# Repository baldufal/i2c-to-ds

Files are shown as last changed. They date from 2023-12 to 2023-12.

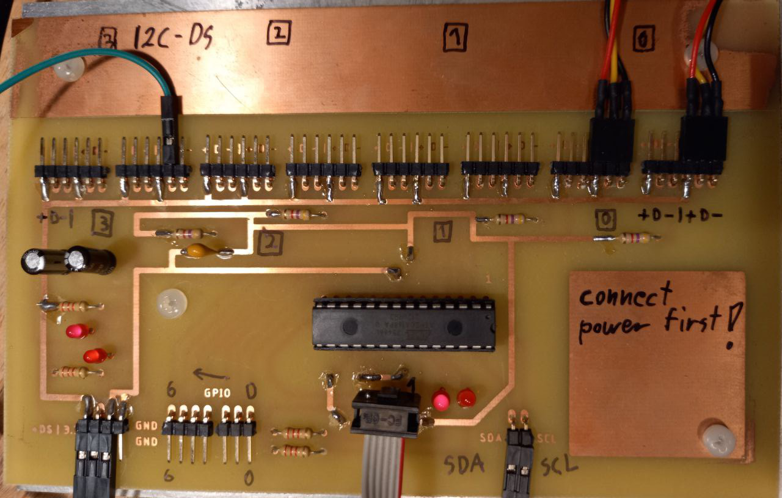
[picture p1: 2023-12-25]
Board/pcb.jpg

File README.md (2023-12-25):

# DS to I2C Expander
Software for Atmega**8 for connecting up to 40 DS18b20 devices to one I2C bus.

We have many DS sensors and didn't want to/couldn't connect them all to a Raspberry Pi due to lack of pins.
We therefore created a small breakout board with an ATmega168(L) on it to read the sensors and make readings available via I2C.
The devices are connected to 4 1-wire buses, which can be searched and read out through setting bits in the control register at `0x00`.

## Board
The board provides 4 independent 1-Wire buses with 4 3-pin connectors each.
The DS are powered by 5V, but the data line is pulled up to 3.3V (which is the supply voltage of the Atmega).

Additionally there are 7 GPIO pins on the board, that can also be controlled via I2C.

For monitoring/debugging, there are 2 LEDs that indicate working 3.3V and 5V voltages.
Another 2 LEDs are controlled by the mC and indicate healthy operation (blinking @ 1Hz) and ongoing readouts (second LED on).

## I2C Interface
The device address is `0x3f`.
The I2C interface exposes 254 8bit registers:
Register | Semantics | Allowed values (writing)
---|---|---
0 | Controlling 1-Wire buses | 1 / 2 / 4 / 8 / 16
1 | GPIO Data Direction | 0-127
2 | GPIO Values | 0-127
3 | CRC over following bytes| -
4 | Length n | -
5 | Data Byte 1 | -
6 | Data Byte 2| -
7 | ... | -
n+4 | Data Byte n-1 | -

- Register 1 allows reading/setting the data direction (input or output) of the 7 GPIO pins.
- Register 2 allows reading the state of input GPIOs and setting the state of output GPIOs.
- The CRC is the 1-Wire CRC8. It is computed over register 4 and the following (actually used!) data bytes (end defined by the content of register 4).
- Register 4 contains the number of data bytes that follow. All other registers will read as 0.

During 1-Wire operations, no I2C communication is possible (interrupts disabled)!

## 1-Wire commands
The four 1-Wire buses can be controlled by setting any of the 5 LSBs in the command register (only one at a time).

Bits 0 to 3 will trigger a device search on the corresponding 1-Wire bus.
After ~1s, the data bytes will contain an ordered list of all addresses on this bus.

Bit 4 will trigger the conversion (actual measurement of temperatures by DSs) of all devices on all buses.
After ~1s, the data bytes will contain the temperature data. This consists of 2 bytes per DS, as specified in the data sheet.

The conversion command depends on the 1-Wire addresses, that were previously found by the device search command(s).
A search on bus 0 will first reset all addresses. A search on any bus must not be triggered after a search on a bus with higher index was triggered.
It is thereby strongly advised to set bits 0 to 3 in this order for initialization and then only set bit 3 for readout.

## Test scripts
There are two python scripts, that allow sending 1-Wire commands and reading/setting GPIO values from a terminal on a Raspberry Pi.

## License
MIT, but would be nice if you would link back here.

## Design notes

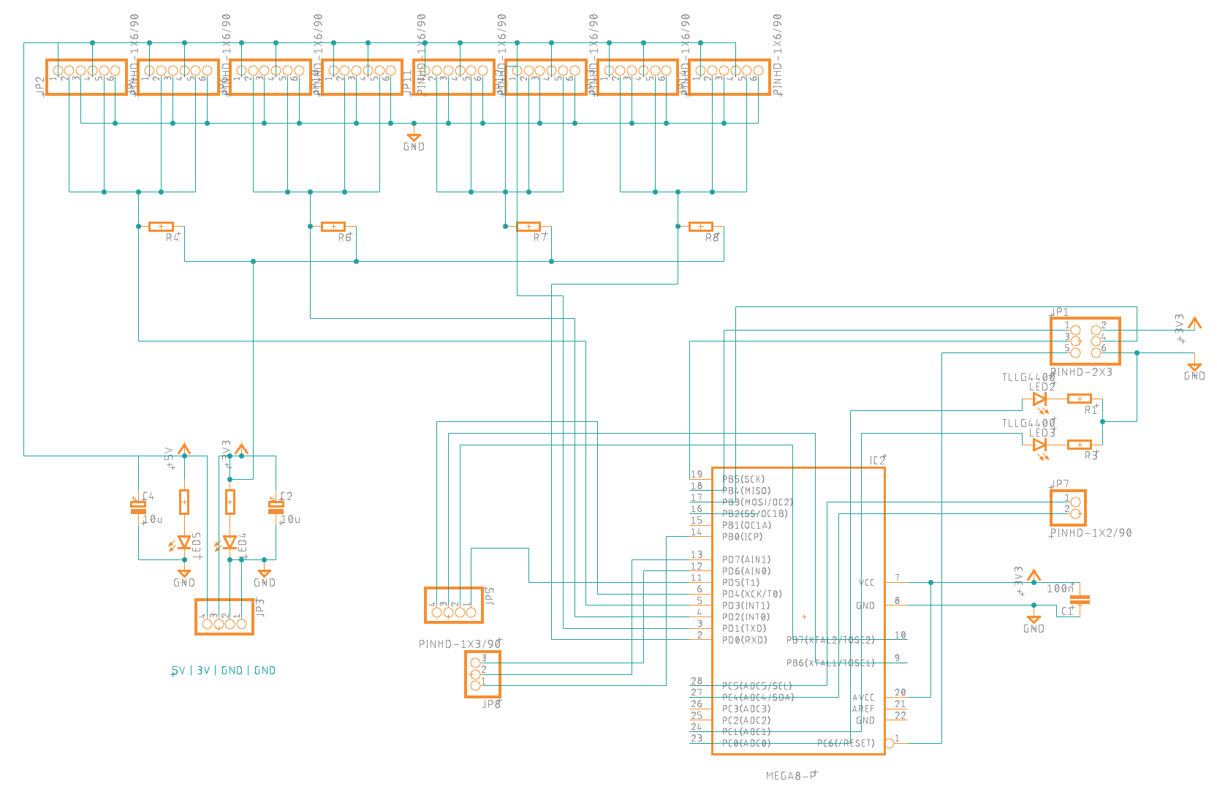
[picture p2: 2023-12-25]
Board/schematic.PNG

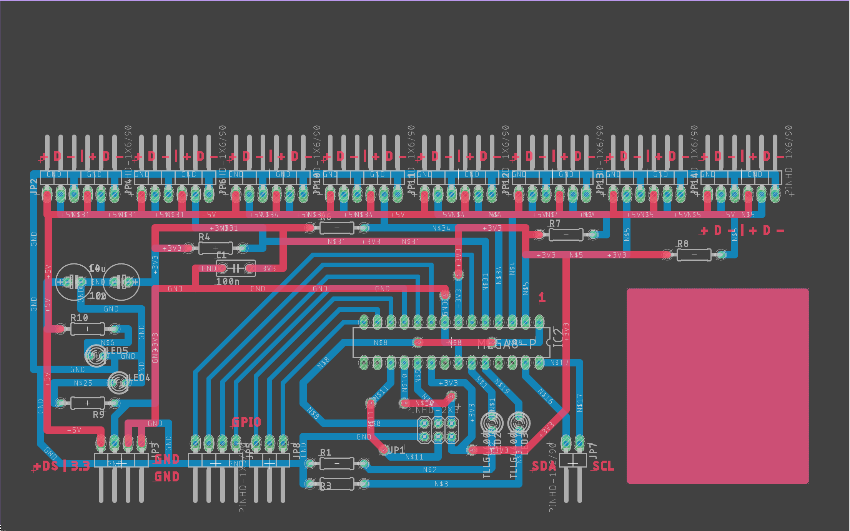
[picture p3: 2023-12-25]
Board/board.PNG

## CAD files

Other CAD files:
Board/I2C-DS ED v35.f3z

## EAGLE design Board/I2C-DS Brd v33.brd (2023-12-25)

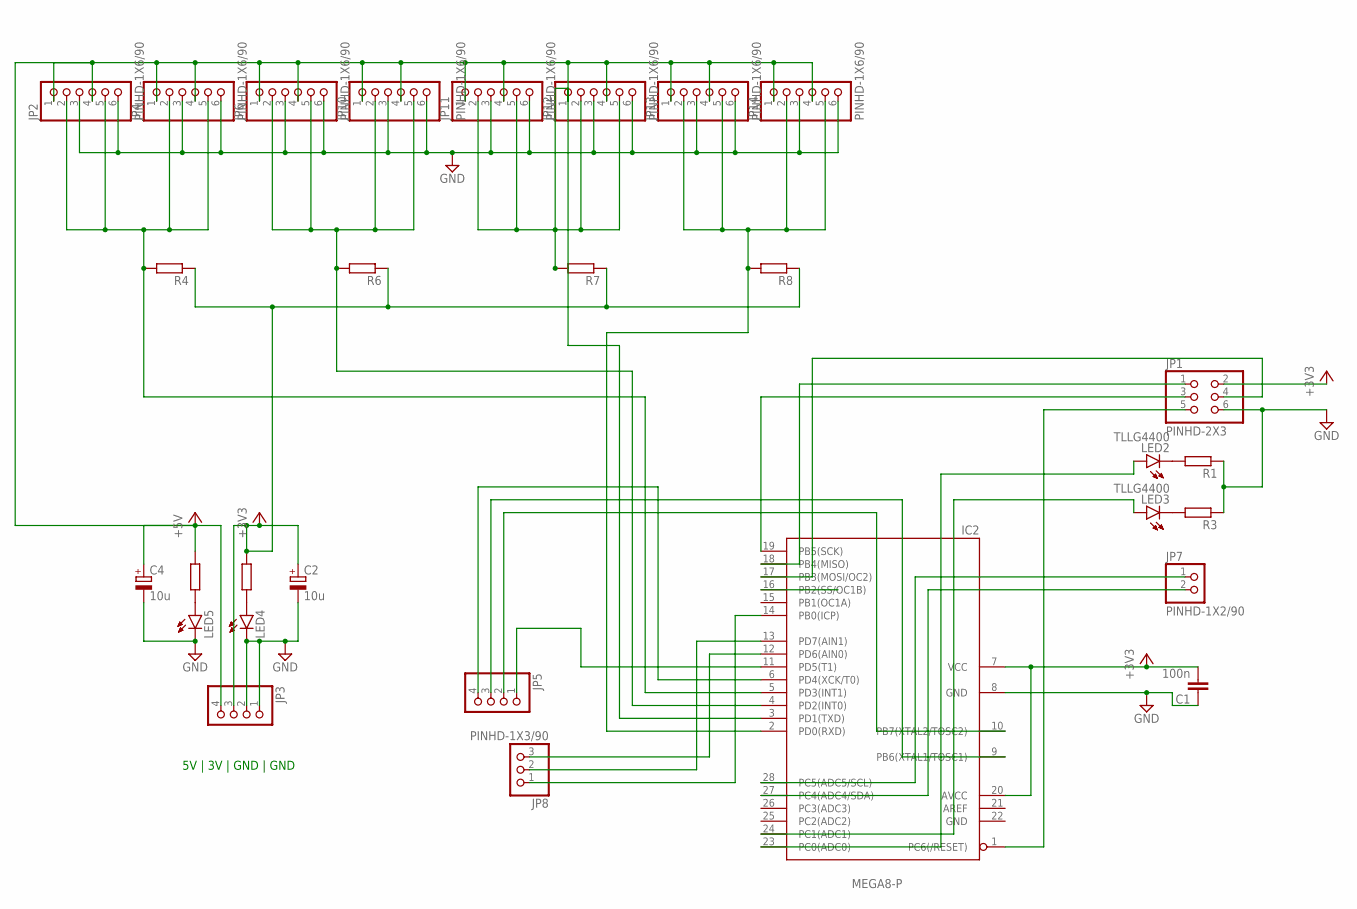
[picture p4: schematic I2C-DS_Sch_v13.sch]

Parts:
C1: 100n; C050-030X075
C2, C4: 10u; E2,5-7
IC2: MEGA8-P; DIL28-3
JP1: PINHD-2X3; 2X03
JP2, JP4, JP6, JP10, JP11, JP12, JP13, JP14: PINHD-1X6/90; 1X06/90
JP3, JP5: PINHD-1X4/90; 1X04/90
JP7: PINHD-1X2/90; 1X02/90
JP8: PINHD-1X3/90; 1X03/90
LED2, LED3: TLLG4400; LED3MM
LED4, LED5: LED3MM
R1, R3, R4, R6, R7, R8, R9, R10: R-EU_0207/10; 0207/10

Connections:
+3V3: C1.2, C2.+, IC2.7 (VCC), IC2.20 (AVCC), JP1.2, JP3.3, R4.1, R6.1, R7.1, R8.1, R9.1
+5V: C4.+, JP2.1, JP2.4, JP3.4, JP4.1, JP4.4, JP6.1, JP6.4, JP10.1, JP10.4, JP11.1, JP11.4, JP12.1, JP12.4, JP13.1, JP13.4, JP14.1, JP14.4, R10.1
GND: C1.1, C2.-, C4.-, IC2.8 (GND), IC2.22 (GND), JP1.6, JP2.3, JP2.6, JP3.1, JP3.2, JP4.3, JP4.6, JP6.3, JP6.6, JP10.3, JP10.6, JP11.3, JP11.6, JP12.3, JP12.6, JP13.3, JP13.6, JP14.3, JP14.6, LED4.K (C), LED5.K (C), R1.1, R3.1
unnamed: IC2.23 (PC0(ADC0)), LED2.A
unnamed: LED2.K (C), R1.2
unnamed: LED3.K (C), R3.2
unnamed: IC2.3 (PD1(TXD)), JP11.2, JP11.5, JP12.2, JP12.5, R7.2
unnamed: IC2.2 (PD0(RXD)), JP13.2, JP13.5, JP14.2, JP14.5, R8.2
unnamed: LED5.A, R10.2
unnamed: IC2.13 (PD7(AIN1)), JP8.2
unnamed: IC2.1 (PC6(/RESET)), JP1.5
unnamed: IC2.19 (PB5(SCK)), JP1.3
unnamed: IC2.18 (PB4(MISO)), JP1.1
unnamed: IC2.17 (PB3(MOSI/OC2)), JP1.4
unnamed: IC2.6 (PD4(XCK/T0)), JP5.4
unnamed: IC2.11 (PD5(T1)), JP5.1
unnamed: IC2.9 (PB6(XTAL1/TOSC1)), JP5.3
unnamed: IC2.10 (PB7(XTAL2/TOSC2)), JP5.2
unnamed: IC2.27 (PC4(ADC4/SDA)), JP7.2
unnamed: IC2.28 (PC5(ADC5/SCL)), JP7.1
unnamed: IC2.24 (PC1(ADC1)), LED3.A
unnamed: IC2.12 (PD6(AIN0)), JP8.3
unnamed: IC2.14 (PB0(ICP)), JP8.1
unnamed: LED4.A, R9.2
unnamed: IC2.5 (PD3(INT1)), JP2.2, JP2.5, JP4.2, JP4.5, R4.2
unnamed: IC2.4 (PD2(INT0)), JP6.2, JP6.5, JP10.2, JP10.5, R6.2

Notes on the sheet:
5V | 3V | GND | GND

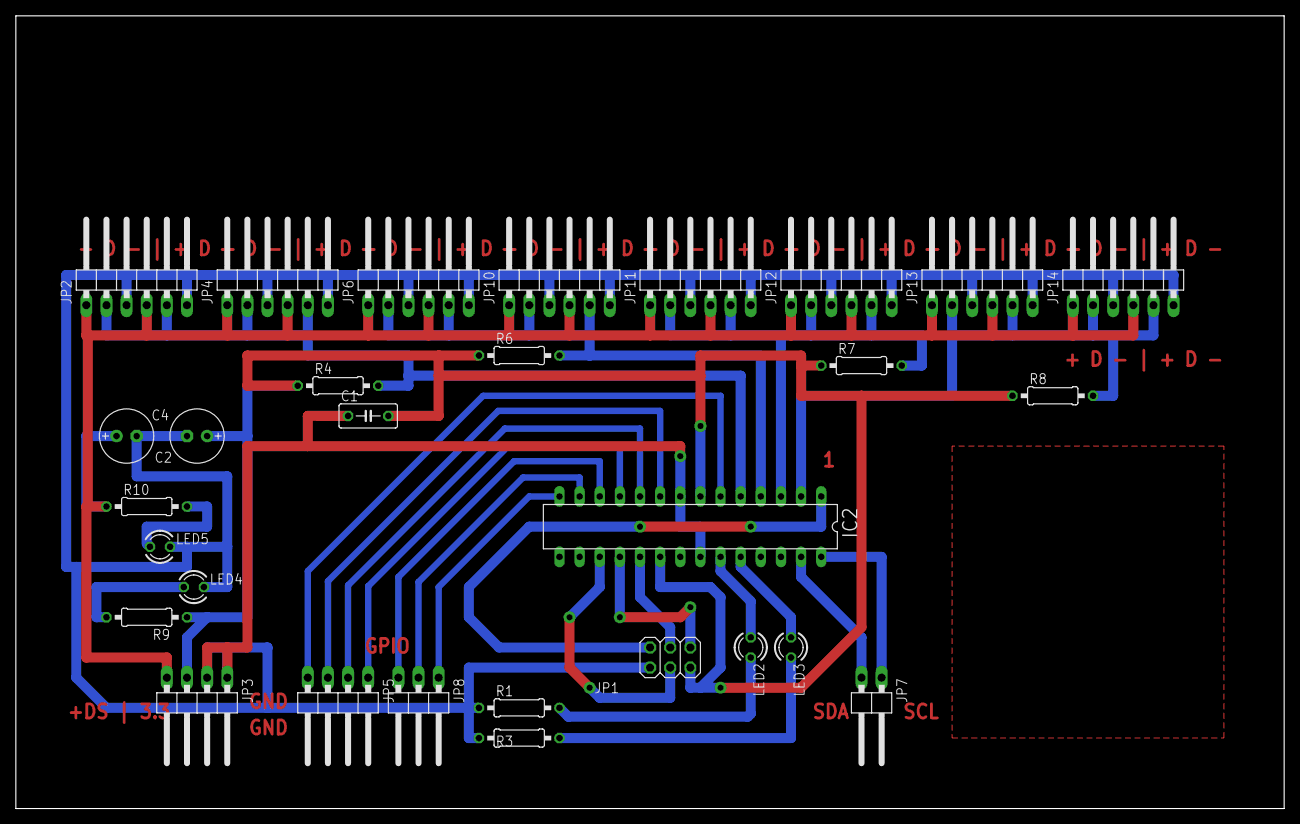
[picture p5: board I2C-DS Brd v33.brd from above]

Board: 2 copper layers, 160.0 x 100.0 mm, 29 parts (0 on the bottom side), 26 nets.

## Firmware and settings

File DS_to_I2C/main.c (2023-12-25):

// Inspired by https://gist.github.com/stecman/9ec74de5e8a5c3c6341c791d9c233adc

#ifndef F_CPU
# define F_CPU 8000000UL
#endif

//1Wire
#include "ds18b20.h"
#include "onewire.h"
#include "pindef.h"

//I2C
#include "twislave.h"

//CRC
#include "crc.h"

// AVR
#include <avr/io.h>
#include <util/delay.h>
#include <avr/interrupt.h>
#include <avr/wdt.h>

// C
#include <string.h>


// I2C slave address.
#define I2C_SLAVE_ADRESS 0x3F

// Status register flags.
#define BIT_INIT_BUS0 0x01
#define BIT_INIT_BUS1 0x02
#define BIT_INIT_BUS2 0x04
#define BIT_INIT_BUS3 0x08
#define BIT_READOUT 0x10



const static gpin_t busPins[4] = {
	{ &PORTD, &PIND, &DDRD, PIND0 },
	{ &PORTD, &PIND, &DDRD, PIND1 },
	{ &PORTD, &PIND, &DDRD, PIND2 },
	{ &PORTD, &PIND, &DDRD, PIND3 }};


	// Contains all known 1wire addresses. 8 Bytes each.
	// First all on bus 1, then bus 3, ...
	static uint8_t deviceAddresses[400];
	// Contains how many devices there are on bus 1 .. 4.
	static uint8_t deviceCounts[4];


	static void io_init(){
		// 1Wire busses: PD0..PD3
		// 7 "GPIO" pins: B0, D7, D6, D5, B7, B6, D4
		// LEDs: C0 (1Hz alive signal), C1 (="1Wire action in progress")
		
		// LEDs as outputs
		DDRC |= 0b00000011;
		// LEDs off
		PORTC &= ~0b00000011;
		
		// Bus and GPIO pins are continuously managed during execution
	}
	

	static void syncGPIO(){
		// 7 "GPIO" pins: B0, D7, D6, D5, B7, B6, D4
		
		// 0 -> B0
		if(i2cdata[1] & (1<<0)){
			DDRB |=  (1<< DDRB0);
			if(i2cdata[2] & (1<<0)){
				PORTB |= (1<<PORTB0);
				}else{
				PORTB &= ~(1<<PORTB0);
			}
			}else{
			DDRB &= ~(1<<DDRB0);
			i2cdata[2] &= ~(1<<0);
			if(PINB & (1<<PINB0))
			i2cdata[2] |= (1<<0);
		}
		// 1 -> D7
		if(i2cdata[1] & (1<<1)){
			DDRD |=  (1<< DDRD7);
			if(i2cdata[2] & (1<<1)){
				PORTD |= (1<<PORTD7);
				}else{
				PORTD &= ~(1<<PORTD7);
			}
			}else{
			DDRD &= ~(1<<DDRD7);
			i2cdata[2] &= ~(1<<1);
			if(PIND & (1<<PIND7))
			i2cdata[2] |= (1<<1);
		}
		// 2 -> D6
		if(i2cdata[1] & (1<<2)){
			DDRD |=  (1<< DDRD6);
			if(i2cdata[2] & (1<<2)){
				PORTD |= (1<<PORTD6);
				}else{
				PORTD &= ~(1<<PORTD6);
			}
			}else{
			DDRD &= ~(1<<DDRD6);
			i2cdata[2] &= ~(1<<2);
			if(PIND & (1<<PIND6))
			i2cdata[2] |= (1<<2);
		}
		// 3 -> D5
		if(i2cdata[1] & (1<<3)){
			DDRD |=  (1<< DDRD5);
			if(i2cdata[2] & (1<<3)){
				PORTD |= (1<<PORTD5);
				}else{
				PORTD &= ~(1<<PORTD5);
			}
			}else{
			DDRD &= ~(1<<DDRD5);
			i2cdata[2] &= ~(1<<3);
			if(PIND & (1<<PIND5))
			i2cdata[2] |= (1<<3);
		}
		// 4 -> B7
		if(i2cdata[1] & (1<<4)){
			DDRB |=  (1<< DDRB7);
			if(i2cdata[2] & (1<<4)){
				PORTB |= (1<<PORTB7);
				}else{
				PORTB &= ~(1<<PORTB7);
			}
			}else{
			DDRB &= ~(1<<DDRB7);
			i2cdata[2] &= ~(1<<4);
			if(PINB & (1<<PINB7))
			i2cdata[2] |= (1<<4);
		}
		// 5 -> B6
		if(i2cdata[1] & (1<<5)){
			DDRB |=  (1<< DDRB6);
			if(i2cdata[2] & (1<<5)){
				PORTB |= (1<<PORTB6);
				}else{
				PORTB &= ~(1<<PORTB6);
			}
			}else{
			DDRB &= ~(1<<DDRB6);
			i2cdata[2] &= ~(1<<5);
			if(PINB & (1<<PINB6))
			i2cdata[2] |= (1<<5);
		}
		// 6 -> D4
		if(i2cdata[1] & (1<<6)){
			DDRD |=  (1<< DDRD4);
			if(i2cdata[2] & (1<<6)){
				PORTD |= (1<<PORTD4);
				}else{
				PORTD &= ~(1<<PORTD4);
			}
			}else{
			DDRD &= ~(1<<DDRD4);
			i2cdata[2] &= ~(1<<6);
			if(PIND & (1<<PIND4))
			i2cdata[2] |= (1<<6);
		}
	}

	// Search all devices of a specific bus.
	// Result is written into deviceAddresses[] and i2cdata[].
	static void _searchDevices(uint8_t busIndex){
		memset(i2cdata + 3, 0, sizeof(i2cdata) -3);
		
		// Start index of this bus in deviceAddresses[].
		uint8_t addressStartIndex = 0;
		for(uint8_t i = 0; i < busIndex; i++){
			addressStartIndex += 8* deviceCounts[i];
		}
		onewire_reset(busPins + busIndex);
		
		// Prepare a new device search
		onewire_search_state search;
		onewire_search_init(&search);
		
		// Search and dump temperatures until we stop finding devices
		uint8_t foundDevices = 0;
		while (onewire_search(busPins + busIndex, &search)) {
			if (onewire_check_rom_crc(&search)) {
				memcpy(deviceAddresses + addressStartIndex + 8 * foundDevices, search.address, sizeof(search.address));
			}
			foundDevices++;
		}
		deviceCounts[busIndex] = foundDevices;
		
		// Write data to i2c registers.
		uint8_t length = deviceCounts[busIndex] * 8;
		i2cdata[4] = length;
		memcpy(i2cdata + 5, deviceAddresses + addressStartIndex, length);
		i2cdata[3] = crc8(i2cdata + 4, length + 1);
	}

	// Read all devices of a specific bus.
	// Result is written into i2cdata[].
	static void _readDevices(uint8_t busIndex){
		// Start index of this bus in deviceAddresses[].
		uint8_t addressStartIndex = 0;
		// Start index of this bus in i2cdata[].
		uint8_t i2cStartIndex = 5;
		for(uint8_t i = 0; i < busIndex; i++){
			addressStartIndex += 8 * deviceCounts[i];
			i2cStartIndex += 2 * deviceCounts[i];
		}
		
		for(uint8_t i = 0; i < deviceCounts[busIndex]; i++){
			uint16_t reading = ds18b20_read_slave(busPins + busIndex, deviceAddresses + addressStartIndex + 8 * i);
			//uint8_t i2cIndex = i2cStartIndex + 2 * i;
			//reading = (i2cIndex << 8) | busIndex; // For debugging only.
			memcpy(i2cdata + i2cStartIndex + 2 * i, &reading, sizeof(reading));
		}
	}


	static void handleStatusByte(){
		// Return if nothing to do
		if((i2cdata[0] & 0b00011111) == 0x00)
		return;
		
		// Enable readout LED
		PORTC |= 0x02;
		
		switch(i2cdata[0]){
			case BIT_INIT_BUS0:
			// When initializing bus 0 we reset all known addresses.
			memset(deviceAddresses, 0, sizeof(deviceAddresses));
			memset(deviceCounts, 0, sizeof(deviceCounts));
			
			_searchDevices(0);
			break;
			
			case BIT_INIT_BUS1:
			_searchDevices(1);
			break;
			
			case BIT_INIT_BUS2:
			_searchDevices(2);
			break;
			
			case BIT_INIT_BUS3:
			_searchDevices(3);
			break;
			
			case BIT_READOUT:
			{
				// Start conversion
				ds18b20_convert(busPins + 0);
				ds18b20_convert(busPins + 1);
				ds18b20_convert(busPins + 2);
				ds18b20_convert(busPins + 3);
				
				/*
				// Start conversion for every device independently.
				uint8_t addressStartIndex = 0;
				for(uint8_t busIndex = 0; busIndex < 4; busIndex++){
				for(uint8_t deviceIndex = addressStartIndex; deviceIndex < addressStartIndex + deviceCounts[busIndex]; deviceIndex++){
				ds18b20_convert_single(busPins + busIndex,deviceAddresses + 8 * deviceIndex);
				}
				addressStartIndex += deviceCounts[busIndex];
				}
				*/
				
				// Wait for conversion to complete.
				_delay_ms(750);
				
				// Clear result.
				memset(i2cdata + 3, 0, sizeof(i2cdata) - 3);
				
				// Get results.
				_readDevices(0);
				_readDevices(1);
				_readDevices(2);
				_readDevices(3);
				
				// Set length and crc.
				i2cdata[4] = 2 * (deviceCounts[0] + deviceCounts[1] + deviceCounts[2] + deviceCounts[3]);
				i2cdata[3] = crc8(i2cdata + 4, i2cdata[4] + 1);
				break;
			}
		}
		
		// Clear action bits
		i2cdata[0x00] &= 0b11100000;
		// Disable readout LED
		PORTC &= ~0x02;
	}


	int main(void)
	{
		memset(i2cdata, 0, sizeof(i2cdata));
		memset(deviceAddresses, 0, sizeof(deviceAddresses));
		memset(deviceCounts, 0, sizeof(deviceCounts));
		
		io_init();
		
		// Enable I2C.
		init_twi_slave(I2C_SLAVE_ADRESS);
		
		// Enable watchdog to restart if we didn't reset it for 2 seconds.
		wdt_enable(WDTO_2S);
		
		while(1){
			// Disable interrupts.
			cli();
			
			syncGPIO();
			handleStatusByte();
			
			// Enable interrupts.
			sei();
			
			_delay_ms(500);
			
			// Toggle health LED
			PORTC ^= (1<<PORTC0);
			
			// Reset watchdog timer.
			wdt_reset();
		}

		return 0;
	}

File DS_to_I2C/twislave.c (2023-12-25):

/*
* twislave.c
*
* Created: 23-Dec-21 5:35:30 PM
* Author: Falk
* Source: https://rn-wissen.de/wiki/index.php/TWI_Slave_mit_avr-gcc
*
* We support all three types of I2C transactions:
* - Pure write: One byte can be written to address 0x00, 0x01 or 0x02.
*	0x00 is the status register. 0x01 and 0x02 configure the 7 GPIO pins

* - Pure read: 254 bytes can be read, starting from address 0x00.
*    The data consists of one status byte (at 0x0), two bytes for GPIO, a CRC byte, a length byte and either DS addresses or temperatures.
* - Write+read: This is actually just a read from some given address (the one byte written).
*/

#include <util/twi.h>
#include <avr/interrupt.h>
#include <stdint.h>
#include "twislave.h"

// The currently selected register address (within i2cdata) to be read from/written to.
volatile uint8_t buffer_addr;

void init_twi_slave(uint8_t addr)
{
	// I2C addresses are 7 bits! We have to shift.
	TWAR=(addr<<1);
	TWCR &= ~((1<<TWSTA)|(1<<TWSTO));
	TWCR|= (1<<TWEA) | (1<<TWEN)|(1<<TWIE);
	buffer_addr=0xFF;
}

// Macros for TWI bitmasks

// ACK nach empfangenen Daten senden/ ACK nach gesendeten Daten erwarten
#define TWCR_ACK TWCR = (1<<TWEN)|(1<<TWIE)|(1<<TWINT)|(1<<TWEA)|(0<<TWSTA)|(0<<TWSTO)|(0<<TWWC);

// NACK nach empfangenen Daten senden/ NACK nach gesendeten Daten erwarten
#define TWCR_NACK TWCR = (1<<TWEN)|(1<<TWIE)|(1<<TWINT)|(0<<TWEA)|(0<<TWSTA)|(0<<TWSTO)|(0<<TWWC);

// Switch to the non-addressed slave mode...
#define TWCR_RESET TWCR = (1<<TWEN)|(1<<TWIE)|(1<<TWINT)|(1<<TWEA)|(0<<TWSTA)|(1<<TWSTO)|(0<<TWWC);

// TWI interrupt service routine
ISR (TWI_vect)
{
	uint8_t data=0;

	// Check TWI status register
	switch (TW_STATUS)
	{
		// Slave Receiver

		// 0x60 Slave Receiver, Slave was addressed
		case TW_SR_SLA_ACK:
		// Receive next byte of data, send ACK afterwards
		TWCR_ACK;
		// Set "register address" to undefined
		buffer_addr=0xFF;
		break;
		
		// 0x80 Slave Receiver, a byte of data has been received
		case TW_SR_DATA_ACK:
		// Read received data
		data=TWDR;
		
		// First access of this transaction, set register address
		if (buffer_addr == 0xFF) {
			// First byte of this transaction
			// This specifies the register address, usually.
			if (data < i2c_buffer_size) {
				buffer_addr = data;
			}

			// Receive next byte, ACK afterwards to request next byte
			TWCR_ACK;

		} else {
			// Subsequent byte(s) of this transaction
			// We can now receive data and use it.
			
			// We allow writing the status register 0x00 and GPIO registers 0x01 and 0x02
			if(buffer_addr == 0x00)
			{
				// We only allow setting bit 0 OR 1 OR 2 or 3 or 4.
				if (data == 0x01 || data == 0x02 || data == 0x04 || data == 0x08 || data == 0x10) {
					// Write request to status register
					i2cdata[buffer_addr] &= 0b11100000;
					i2cdata[buffer_addr] |= data;
				}
			}
			if (buffer_addr == 0x01 || buffer_addr == 0x02)
			{
				i2cdata[buffer_addr] &= 0b10000000;
				i2cdata[buffer_addr] |= (data & 0b01111111);
			}

			// Increase address for subsequent writes (which are not supported)
			buffer_addr++;

			// Receive next byte, ACK afterwards to request next byte
			TWCR_ACK;
		}
		break;


		//Slave transmitter

		//0xA8 Slave wurde im Lesemodus adressiert und hat ein ACK zurückgegeben.
		case TW_ST_SLA_ACK:
		// fallthrough

		// 0xB8 Slave Transmitter, data requested
		case TW_ST_DATA_ACK:

		if (buffer_addr == 0xFF)
		{
			// This is either a pure read transaction (no Write+Read) or something else went wrong.
			// We'll just assume they want to read everything...
			buffer_addr=0x00;
		}
		
		if(buffer_addr<i2c_buffer_size+1)
		{
			// Send one byte of data
			TWDR = i2cdata[buffer_addr];
			// Auto increment address
			buffer_addr++;
		} else {
			// Invalid address/read too many bytes/... -- we send 0xFE as an error
			TWDR=0xFE;
		}
		TWCR_ACK;
		break;

		case TW_SR_STOP:
		TWCR_ACK;
		break;
		case TW_ST_DATA_NACK: // 0xC0 Keine Daten mehr gefordert
		case TW_SR_DATA_NACK: // 0x88
		case TW_ST_LAST_DATA: // 0xC8  Last data byte in TWDR has been transmitted (TWEA = “0”); ACK has been received
		default:
		TWCR_RESET;
		break;
		
	}
}

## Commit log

2023-12-25 Add board and test files
    [I2C-DS Brd v33.brd, I2C-DS ED v35.f3z, I2C-DS_Sch_v13.sch]
2023-12-25 Mention device address
